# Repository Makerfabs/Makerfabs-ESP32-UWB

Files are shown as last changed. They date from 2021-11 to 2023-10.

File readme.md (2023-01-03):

# Makerfabs ESP32 UWB & Display

```c++
/*
Version:		V4.3
Author:			Vincent
Create Date:	2021/11/6
Note:
	2021/12/9 	V2.0:Add a Indoor Positioning demo.
	2022/6/29 	V2.1:Add DW3000 library.
	2022/8/1  	V3.0:Provides a library available for high-power versions. Move DW3000 to other 		  					     repositories.
	2022/9/6	V3.1:Added changes to the high-power version.
	2022/10/26 	V4.0:Add new version with SSD1306
	2022/11/15	V4.1:Change library name to mf_DW1000.zip
	2022/12/29	V4.2: Change wiki link
	2023/1/3	V4.3: Change directory name.
*/
```
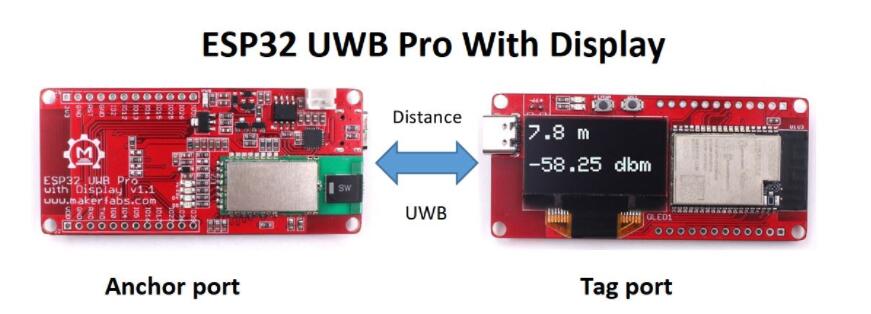
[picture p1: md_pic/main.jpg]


[toc]

# Makerfabs

[Makerfabs home page](https://www.makerfabs.com/)

[Makerfabs Wiki](https://wiki.makerfabs.com/)

# Makerfabs ESP32 UWB Serials
## Intruduce

ESP32 UWB : [esp32-uwb-ultra-wideband](https://www.makerfabs.com/esp32-uwb-ultra-wideband.html) 

ESP32 UWB Pro : [esp32-uwb-high-power](https://www.makerfabs.com/esp32-uwb-high-power-120m.html)

ESP32 UWB Pro with Display : [ESP32 UWB Pro with Display](https://www.makerfabs.com/esp32-uwb-pro-with-display.html)

Wiki Link : [ESP32 UWB Pro with Display](https://wiki.makerfabs.com/ESP32_UWB_Pro_with_Display.html) 

Ultra-wideband (UWB) is a short-range, wireless communication protocol that operates through radio waves, enables secure reliable ranging and precision sensing, creating a new dimension of spatial context for wireless devices.

This new ESP32 UWB pro with display is the updated version of ESP32 UWB Pro, with the following new spec:

- On-board OLED, 1.3” 128*64, so the distance results can be directly displayed
- Lipo battery charger& connector, so this module can work separately with batteries
- Update UWB position, so the module can be directly installed into a case

| | **UWB Basic** | **UWB Pro** | **UWB Pro with Display** | **UWB DW3000** |
| --- | --- | --- | --- | --- |
| CPU | ESP32-WROOM/WROVER | ESP32-WROVER | ESP32-WROVER | ESP32-WROOM/WROVER |
| Core UWB | DW1000 | DW1000 | DW1000 | DW3000 |
| Screen | N | N | Y | N |
| Measuring distance(m) | 45 | 200 | 200 | 20 |
| Battery Socket | N | N | Y | N |
| UWB Channel | 2/5 | 2/5 | 2/5 | 5/9 |
| Apple Interoperable | N | N | N | Y |
| Suitable for | Normal Testing | Long distance needed | Long distance needed | Product development |

### UWB Basic

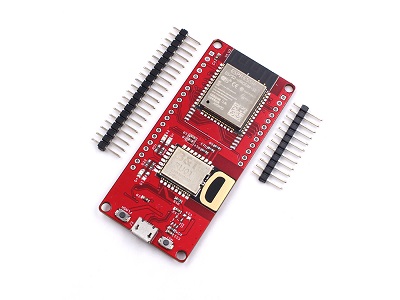
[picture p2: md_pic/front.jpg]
front


### UWB Pro

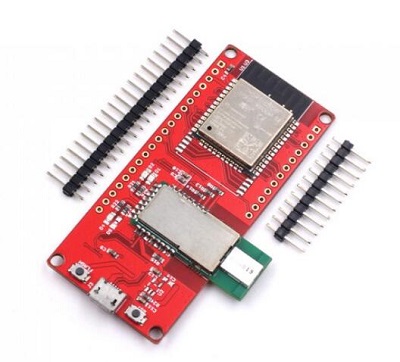
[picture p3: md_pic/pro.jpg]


### UWB Pro with Display

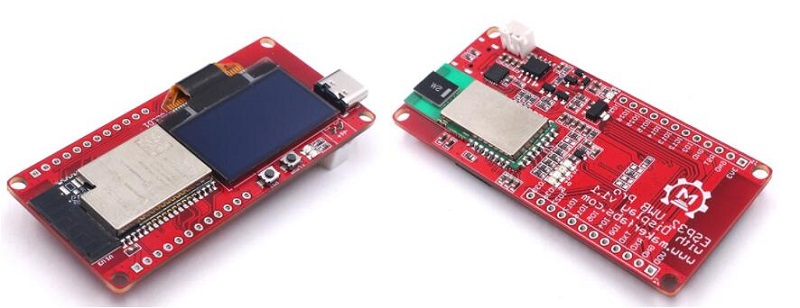
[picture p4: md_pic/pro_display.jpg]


# Example

## Compiler Options

**If you have any questions，such as how to install the development board, how to download the code, how to install the library. Please refer to :[Makerfabs_FAQ](https://github.com/Makerfabs/Makerfabs_FAQ)**

- Install board : ESP32 .
- Rename mf_DW1000.zip to DW1000.zip and install it.
- Install library : Adafruit_SSD1306
- Upload code, select board "ESP32 DEV"

**This library was modified from the [DW1000](https://github.com/thotro/arduino-dw1000) library to work with the Makerfabs hardware. **

**Please download the latest version from our Github.**

## Example List

### uwb_tag

*For ESP32 UWB and ESP32 UWB Pro*

Distance to the receiving end of the test. You need an anchor point to receive data.

### uwb_tag_display

*For ESP32 UWB Pro with display*

Distance to the receiving end of the test. You need an anchor point to receive data.

### anchor

*For ESP32 UWB and ESP32 UWB Pro*

Distance test anchor point.

### anchor_display

*For ESP32 UWB Pro with display*

Distance test anchor point.

### Indoor positioning

*For ESP32 UWB and ESP32 UWB Pro*

Three UWB modules were used for indoor plane positioning. Data is transmitted through UDP protocol and graphically displayed in Python. 

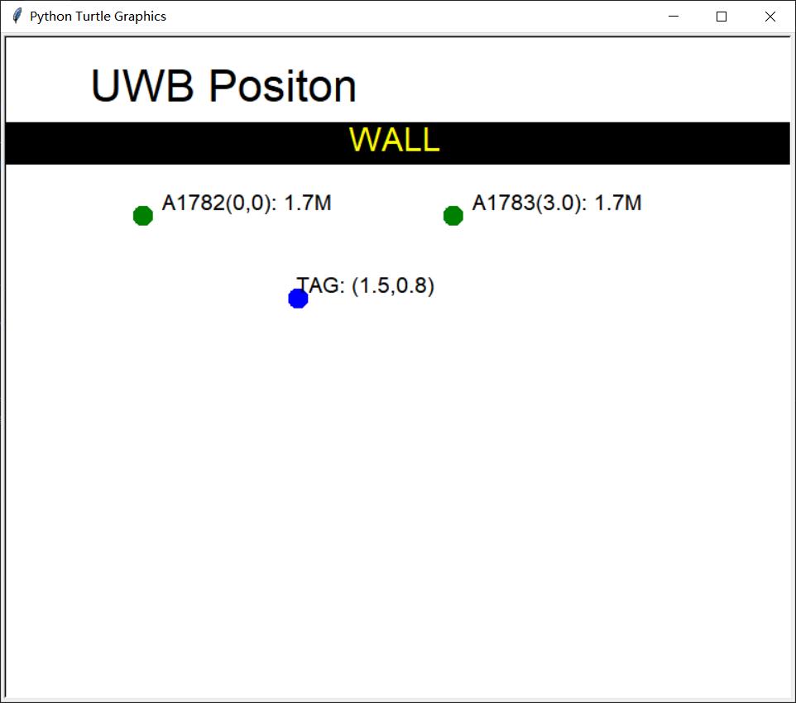
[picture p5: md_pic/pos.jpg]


The law of cosines is used to calculate tag coordinates.

```python
def tag_pos(a, b, c):
    # p = (a + b + c) / 2.0
    # s = cmath.sqrt(p * (p - a) * (p - b) * (p - c))
    # y = 2.0 * s / c
    # x = cmath.sqrt(b * b - y * y)
    cos_a = (b * b + c*c - a * a) / (2 * b * c)
    x = b * cos_a
    y = b * cmath.sqrt(1 - cos_a * cos_a)

    return round(x.real, 1), round(y.real, 1)
```

## Pin Define

### ESP32 UWB and ESP32 UWB Pro

```c++
#define SPI_SCK 18
#define SPI_MISO 19
#define SPI_MOSI 23

#define DW_CS 4
#define PIN_RST 27
#define PIN_IRQ 34
```

### ESP32 Pro with display

```c++
#define SPI_SCK 18
#define SPI_MISO 19
#define SPI_MOSI 23

#define UWB_SS 21   // spi select pin
#define UWB_RST 27  // reset pin
#define UWB_IRQ 34  // irq pin

#define I2C_SDA 4	//I2C screen ssd1306
#define I2C_SCL 5
```

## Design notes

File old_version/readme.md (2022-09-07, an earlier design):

# Makerfabs ESP32 UWB

```c++
/*
Version:		V3.0
Author:			Vincent
Create Date:	2021/11/6
Note:
	2021/12/9 	V2.0:Add a Indoor Positioning demo.
	2022/6/29 	V2.1:Add DW3000 library.
	2022/8/1  	V3.0:Provides a library available for high-power versions. Move DW3000 to other 		  					     repositories.
	2022/9/6	V3.1:Added changes to the high-power version.

*/
```


[toc]

# Makerfabs

[Makerfabs home page](https://www.makerfabs.com/)

[Makerfabs Wiki](https://makerfabs.com/wiki/index.php?title=Main_Page)

# Makerfabs ESP32 UWB
## Intruduce

Product Link ：[esp32-uwb-ultra-wideband](https://www.makerfabs.com/esp32-uwb-ultra-wideband.html) 

Wiki Link : [ESP32_UWB](https://www.makerfabs.com/wiki/index.php?title=ESP32_UWB) 

Makerfabs ESP32 UWB contains an ESP32 and a DW1000 chip.

The DW1000 is a single-chip wireless transceiver based on ultra-wideband technology. The chip enables you to develop cost-effective RTLS solutions that can pinpoint indoor and outdoor positioning to within 10 cm.

The chip provides a new approach to real-time location and indoor location systems, location-based services, wireless sensor networks and the Internet of Things by providing accurate location awareness and communication.

UWB - X1 - PRO module is our decaWave DW1000 chip design company based UWB transceiver module products. After the encapsulation All compatible DWM1000, pin pin to pin, can directly replace to use. The antenna is integrated in the module and all of the rf circuit, power management and clock circuit is equal to one.

Based on our actual tests, the range range of the standard DW1000 is around 47 meters, and the long-distance version can reach 125 meters. Of course, it depends on the test environment.

## Feature

- Integrated ESP32 2.4G WiFi and Bluetooth.
- DW1000 UWB module.
- UWB - X1 - PRO module.(Long range)

### Front:

front

### Back:
back

### Long Range Version UWB-X1-Pro

long

# Example

## Equipment list

- At least two ESP32 UWB

## Compiler Options

**If you have any questions，such as how to install the development board, how to download the code, how to install the library. Please refer to :[Makerfabs_FAQ](https://github.com/Makerfabs/Makerfabs_FAQ)**

- Install board : ESP32 .
- Install library : arduino-dw1000
- Change code in DW1000.cpp

```c++
void DW1000Class::begin(uint8_t irq, uint8_t rst) {
	// generous initial init/wake-up-idle delay
	delay(5);
	// Configure the IRQ pin as INPUT. Required for correct interrupt setting for ESP8266
    	pinMode(irq, INPUT);
	// start SPI
	SPI.begin();

// Change By VINCENT
// #ifndef ESP8266
// 	SPI.usingInterrupt(digitalPinToInterrupt(irq)); // not every board support this, e.g. ESP8266
// #endif

	// pin and basic member setup
	_rst        = rst;
	_irq        = irq;
	_deviceMode = IDLE_MODE;
	// attach interrupt
	//attachInterrupt(_irq, DW1000Class::handleInterrupt, CHANGE); // todo interrupt for ESP8266
	// TODO throw error if pin is not a interrupt pin
	attachInterrupt(digitalPinToInterrupt(_irq), DW1000Class::handleInterrupt, RISING); // todo interrupt for ESP8266
}
```

Comment out these code, or a compilation error will occur.

```c++
// #ifndef ESP8266
// 	SPI.usingInterrupt(digitalPinToInterrupt(irq)); // not every board support this, e.g. ESP8266
// #endif
```

- Upload code, select board "ESP32 DEV"

**V3.0 Update**

Modify by [DW1000](https://github.com/thotro/arduino-dw1000) version 0.9.0

Provides a library available for high-power versions. It is also compatible with the standard DW1000, and in fact only adds an initialization function for the high-power version. Of course, it also includes the changes above.

```c++

// Vincent changes
// For large power moudle
void DW1000Class::large_power_init()
{
	// uint32 reg;
	// reg = dwt_read32bitreg(GPIO_CTRL_ID);
	// reg |= 0x00014000;
	// reg |= 0x00050000;
	// dwt_write32bitreg(GPIO_CTRL_ID, reg);
	// dwt_write16bitoffsetreg(PMSC_ID, PMSC_TXFINESEQ_OFFSET, PMSC_TXFINESEQ_DISABLE);

	byte reg[4];

	readBytes(GPIO_CTRL, 0, reg, 4);

	reg[1] |= 0x40;
	reg[2] |= 0x01;
	reg[2] |= 0x05;

	writeBytes(GPIO_CTRL, 0, reg, 4);

	reg[0] = reg[1] = reg[2] = reg[3] = 0;
	writeBytes(PMSC, 0x26, reg, 2);

	reg[0] = 0xC0;
	reg[1] = 0;
	reg[2] = 0;
	reg[3] = 0;
	writeBytes(TX_CAL, TC_PGDELAY_SUB, reg, 1);

	reg[0] = 0x1f;
	reg[1] = 0x1f;
	reg[2] = 0x1f;
	reg[3] = 0x1f;
	writeBytes(TX_POWER, 0, reg, 4);
}
```

**V3.1 Update**

By changing the channel from Channel5 to Channel2, the distance of UWB-X1-Pro can reach 320M.



This is due to the fact that the X1-Pro's antenna is optimized for Channel2.

But Makerfabs could not provide further technical support, just suggestions from suppliers.

If you're interested, try DW1000_channel2.zip, or make changes directly in the DW1000 library code.





## Example List

### Anchor

Distance test anchor point.

### Tag

Distance to the receiving end of the test. You need an anchor point to receive data.

### Tag_1306

There is an SSD1306 screen receiver, and a data structure for storing multiple anchor points is implemented. (The screen can display a maximum of two anchors, you can modify the font size to show more anchors). You need an anchor point to receive data.

### Indoor positioning

Three UWB modules were used for indoor plane positioning. Data is transmitted through UDP protocol and graphically displayed in Python. 



The law of cosines is used to calculate tag coordinates.

```python
def tag_pos(a, b, c):
    # p = (a + b + c) / 2.0
    # s = cmath.sqrt(p * (p - a) * (p - b) * (p - c))
    # y = 2.0 * s / c
    # x = cmath.sqrt(b * b - y * y)
    cos_a = (b * b + c*c - a * a) / (2 * b * c)
    x = b * cos_a
    y = b * cmath.sqrt(1 - cos_a * cos_a)

    return round(x.real, 1), round(y.real, 1)
```

## Code Explain

- Define Pins

```c++
#define SPI_SCK 18
#define SPI_MISO 19
#define SPI_MOSI 23
#define DW_CS 4

// connection pins
const uint8_t PIN_RST = 27; // reset pin
const uint8_t PIN_IRQ = 34; // irq pin
const uint8_t PIN_SS = 4;   // spi select pin
```

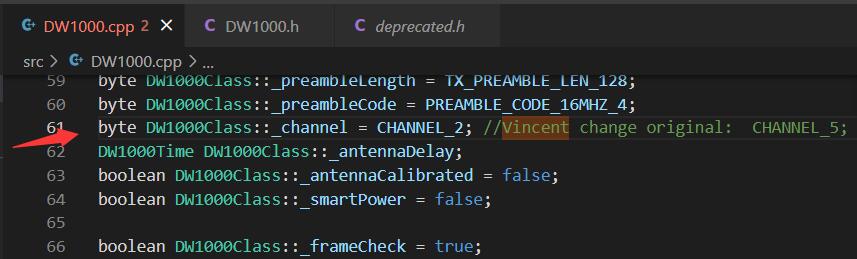
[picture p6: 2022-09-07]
md_pic/v2.jpg

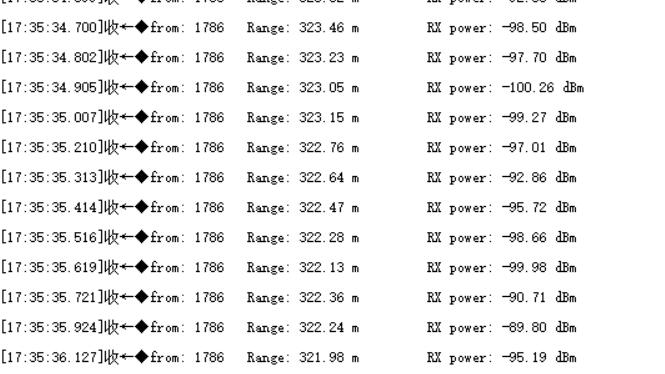
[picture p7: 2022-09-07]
md_pic/pro320m.jpg

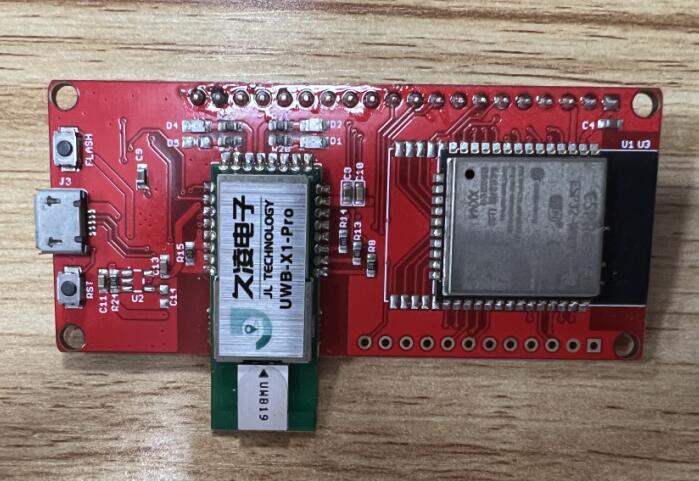
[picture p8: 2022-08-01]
md_pic/long.jpg

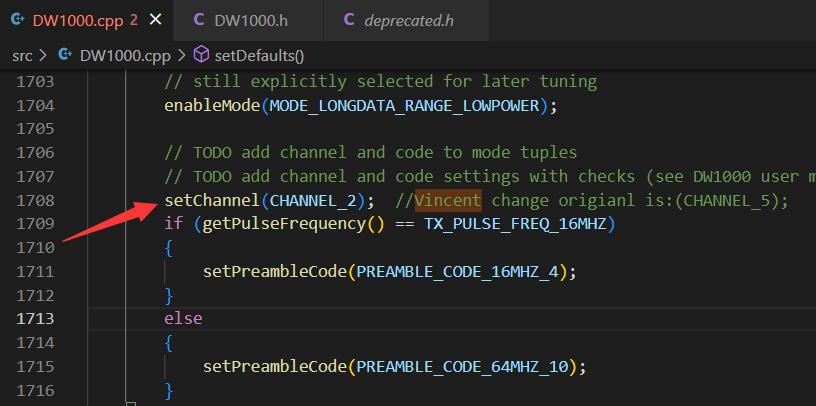
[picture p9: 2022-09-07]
md_pic/v1.jpg

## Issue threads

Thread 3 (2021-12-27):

Apple devices UWB?

exrector, 2021-12-27:
What about iPhone, Apple Watch, AirTag?
It would be nice to use your board as an anchor and my apple devices.  Set the radius and run the required routines from the esp32 repositories.

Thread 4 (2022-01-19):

Antenna tuning / calibration accuracy

alastaira, 2022-01-19:
Hi,

The board design seems good, but I'm getting poor accuracy on the range readings (i.e. when the distance between anchor and tag is consistently reading around 50cm too high). From reading the Decawave documentation, there is an application note regarding antenna calibration, which suggests this could be resolved in either software or hardware design: https://www.decawave.com/wp-content/uploads/2018/10/APS014_Antennna-Delay-Calibration_V1.2.pdf - is that something you've accounted for at all, or can suggest how to incorporate in the library?

Cheers,

pbs-websuntangled, 2022-01-19:
Agreed.i get the same

Also readings are somewhat inconsistent. Rotating the tag or anchor through 90 degrees can add or remove 200mm from the distance reported

Fbo06, 2022-11-03:
hello, got the same issue, do you have found a solution ? thank you for your response

alastaira, 2022-11-03:
> hello, got the same issue, do you have found a solution ? thank you for your response

No, I gave up I'm afraid. Unfortunately I think these boards are not useful for anything other than toys :(

franciscoQM, 2022-11-29:
I came across the same issue. Although I am constantly getting an error of about 0.6 - 0.7+ meters I tested in a distance of from 0-125 meters. I wonder if anyone has found a way of improving the error. For my application all I need is .5 meters

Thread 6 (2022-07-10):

Issues with integrating other SPI devices (?)

XPloadED, 2022-07-10:
Hi,
I'm trying to combine the UWB ranging with the Waveshare 2.9" e-paper display, which also uses SPI. Right now I'm not really sure whats causing the issues. (Maybe conflicting pins? Blocking code somewhere between libraries?).
The Library used for e-paper  display is "GxEPD".
The SPI definition was unchanged in my testings:
```
GxIO_Class io(SPI, /*CS=5*/ SS, /*DC=*/ 17, /*RST=*/ 16); // arbitrary selection of 17, 16
GxEPD_Class display(io, /*RST=*/ 16, /*BUSY=*/ 4); // arbitrary selection of (16), 4
```
As long as I dont run (from GxEPD Lib):
`display.init(115200);`
Ranging works fine, but as soon as I try to combine them I get this multiple times, instead of ranging:

```
Guru Meditation Error: Core  1 panic'ed (Interrupt wdt timeout on CPU1).

Core  1 register dump:
PC      : 0x4008a716  PS      : 0x00060d35  A0      : 0x8008996e  A1      : 0x3ffbedbc
A2      : 0x3ffb7f54  A3      : 0x3ffb8890  A4      : 0x00000004  A5      : 0x00060d23
A6      : 0x00060d23  A7      : 0x00000001  A8      : 0x3ffb8890  A9      : 0x00000018
A10     : 0x3ffb8890  A11     : 0x00000018  A12     : 0x3ffc3414  A13     : 0x00060d23
A14     : 0x007bef68  A15     : 0x003fffff  SAR     : 0x0000001e  EXCCAUSE: 0x00000006
EXCVADDR: 0x00000000  LBEG    : 0x40085e74  LEND    : 0x40085e79  LCOUNT  : 0x00000000
Core  1 was running in ISR context:
EPC1    : 0x400e16d3  EPC2    : 0x00000000  EPC3    : 0x00000000  EPC4    : 0x00000000

Backtrace:0x4008a713:0x3ffbedbc |<-CORRUPTED

Core  0 register dump:
PC      : 0x4008a893  PS      : 0x00060035  A0      : 0x80089597  A1      : 0x3ffbe8bc
A2      : 0x3ffbef68  A3      : 0xb33fffff  A4      : 0x0000abab  A5      : 0x00060023
A6      : 0x00060021  A7      : 0x0000cdcd  A8      : 0x0000abab  A9      : 0xffffffff
A10     : 0x3ffc3230  A11     : 0x00000000  A12     : 0x3ffc322c  A13     : 0x00000007
A14     : 0x007bef68  A15     : 0x003fffff  SAR     : 0x0000001a  EXCCAUSE: 0x00000006
EXCVADDR: 0x00000000  LBEG    : 0x00000000  LEND    : 0x00000000  LCOUNT  : 0x00000000

Backtrace:0x4008a890:0x3ffbe8bc |<-CORRUPTED

ELF file SHA256: 0000000000000000

Rebooting...
```

I don't quite know where the issue is. I'm using this for an university project and am also planning on building another version with the new Apple compatible revision. Therefore I have to get this working somehow. I hope someone can help me out.
It's not necessarily an issue with this library, I just cant tell at the moment.

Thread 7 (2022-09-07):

problem with ESP connection

murtadhodaf, 2022-09-07:
i try to upload and compiling data and get this error

```
`Arduino: 1.8.19 (Windows Store 1.8.57.0) (Windows 10), Board: "ESP32 Dev Module, Disabled, Default 4MB with spiffs (1.2MB APP/1.5MB SPIFFS), 240MHz (WiFi/BT), QIO, 80MHz, 4MB (32Mb), 921600, Core 1, Core 1, None"

Sketch uses 240933 bytes (18%) of program storage space. Maximum is 1310720 bytes.
Global variables use 16376 bytes (4%) of dynamic memory, leaving 311304 bytes for local variables. Maximum is 327680 bytes.
esptool.py v3.3
Serial port COM3
Connecting.....................................An error occurred while uploading the sketch
.

A fatal error occurred: Failed to connect to ESP32: Wrong boot mode detected (0x13)! The chip needs to be in download mode.
For troubleshooting steps visit: https://docs.espressif.com/projects/esptool/en/latest/troubleshooting.html`
```
 It try to reset with the sreset button and doesn' work shat should i do ? thx

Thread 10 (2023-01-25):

Watchdog issue on SPI IRC

JulienCarayon, 2023-01-25:
It seems that this line in the DW1000 library is causing issue :

```
attachInterrupt(digitalPinToInterrupt(_irq), DW1000Class::handleInterrupt, RISING);
```
It's causing bootloop and triggers a timout watchdog

Thank you for you help, it would be much much appreciated !

here is the log i have :
```
--- Terminal on /dev/cu.usbserial-028D4616 | 115200 8-N-1
--- Available filters and text transformations: colorize, debug, default, direct, esp32_exception_decoder, hexlify, log2file, nocontrol, printable, send_on_enter, time
--- More details at https://bit.ly/pio-monitor-filters
--- Quit: Ctrl+C | Menu: Ctrl+T | Help: Ctrl+T followed by Ctrl+H
3fff0030,len:1184
load:0x40078000,len:13160
load:0x40080400,len:3036
entry 0x400805e4
E (97) psram: PSRAM ID read error: 0xffffffff
Guru Meditation Error: Core  1 panic'ed (Interrupt wdt timeout on CPU1).

Core  1 register dump:
PC      : 0x4008b9c0  PS      : 0x00060735  A0      : 0x8008ac12  A1      : 0x3ffbed2c
A2      : 0x3ffb7f54  A3      : 0x3ffb8890  A4      : 0x00000004  A5      : 0x00060723
A6      : 0x00060723  A7      : 0x00000001  A8      : 0x3ffb8890  A9      : 0x00000018
A10     : 0x3ffb8890  A11     : 0x00000018  A12     : 0x3ffc1d04  A13     : 0x00060723
A14     : 0x007beed8  A15     : 0x003fffff  SAR     : 0x0000001e  EXCCAUSE: 0x00000006
EXCVADDR: 0x00000000  LBEG    : 0x4008537d  LEND    : 0x40085385  LCOUNT  : 0x00000027
Core  1 was running in ISR context:
EPC1    : 0x400e04b3  EPC2    : 0x00000000  EPC3    : 0x00000000  EPC4    : 0x00000000

Backtrace:0x4008b9bd:0x3ffbed2c |<-CORRUPTED

Core  0 register dump:
PC      : 0x4008bb37  PS      : 0x00060035  A0      : 0x8008a83b  A1      : 0x3ffbe82c
A2      : 0x3ffbeed8  A3      : 0xb33fffff  A4      : 0x0000abab  A5      : 0x00060023
A6      : 0x00060021  A7      : 0x0000cdcd  A8      : 0x0000abab  A9      : 0xffffffff
A10     : 0x3ffc1af0  A11     : 0x00000000  A12     : 0x3ffc1aec  A13     : 0x00000007
A14     : 0x007beed8  A15     : 0x003fffff  SAR     : 0x0000001a  EXCCAUSE: 0x00000006
EXCVADDR: 0x00000000  LBEG    : 0x00000000  LEND    : 0x00000000  LCOUNT  : 0x00000000

Backtrace:0x4008bb34:0x3ffbe82c |<-CORRUPTED

ELF file SHA256: 0000000000000000
```

I've used platformIO to compile with the following versions :
```
Processing esp32dev (platform: espressif32; board: esp32dev; framework: arduino)
---------------------------------------------------------------------------------------------------------------------------------------------
Verbose mode can be enabled via `-v, --verbose` option
CONFIGURATION: https://docs.platformio.org/page/boards/espressif32/esp32dev.html
PLATFORM: Espressif 32 (6.0.0) > Espressif ESP32 Dev Module
HARDWARE: ESP32 240MHz, 320KB RAM, 4MB Flash
DEBUG: Current (cmsis-dap) External (cmsis-dap, esp-bridge, esp-prog, iot-bus-jtag, jlink, minimodule, olimex-arm-usb-ocd, olimex-arm-usb-ocd-h, olimex-arm-usb-tiny-h, olimex-jtag-tiny, tumpa)
PACKAGES:
 - framework-arduinoespressif32 @ 3.20006.221224 (2.0.6)
 - tool-esptoolpy @ 1.40400.0 (4.4.0)
 - toolchain-xtensa-esp32 @ 8.4.0+2021r2-patch5

 ```

gwilsonOSU, 2023-02-08:
I encountered the same issue using the provided example anchor.ino.  I believe the bug is in the following line of code:

`const uint8_t PIN_SS = 22;   // spi select pin`

Changing the pin assignment from 22 to 4 (as it is in the tag version of the code) fixed the issue for me.  The anchor now receives ranges from a tag.

Closed 2023-02-09.

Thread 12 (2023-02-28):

Usb connector part

djObsidian, 2023-02-28:
What is this footprint? I can't find any suitable part for this footprint. The closest avaliable thing was 2013499-1 from TE Connectivity, but its legs are spaced wider than should be here.
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
Part name in schematic is just MICRO-USB-5P, it makes no sense.

greg1985, 2025-04-23:
I know its an old issue, but its still opened and I have encountered same problem so...
Seems it might be U254-051T-4BH83-S1S

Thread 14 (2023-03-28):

The example code can't work with ESP32 UWB Pro with Display

willy20040711, 2023-03-28:
I try to use 3 ESP32 UWB Pro with Display boards. Two anchors and one for tag.
The example code of [indoorIndoorPositioning](https://github.com/Makerfabs/Makerfabs-ESP32-UWB/tree/main/example/IndoorPositioning)  can't work.
The tag only return empty object like: {LINK:[]}

juanelog, 2023-10-26:
Hi Willy
Did you find any solution to this problem?

> I try to use 3 ESP32 UWB Pro with Display boards. Two anchors and one for tag. The example code of [indoorIndoorPositioning](https://github.com/Makerfabs/Makerfabs-ESP32-UWB/tree/main/example/IndoorPositioning) can't work. The tag only return empty object like: {LINK:[]}

I'm trying to do indoor positioning but I have the same result.
Do you have any recommendations?
Thank you

lewthomps, 2023-11-24:
same issue here!

We're either of you able to find a solution to this problem?

Thanks!

lewthomps, 2023-11-24:
nevermind! switchting DW_CS pin to 21 fixed the problem!

scinfu, 2024-01-17:
not working for me change the pint to 21.
I have bought this: https://www.makerfabs.com/mauwb-dw3000-with-stm32-at-command.html

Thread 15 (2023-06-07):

Whera are the LED connected to?

Nachorov027, 2023-06-07:
Hi, I've recently bought 4 of these device for an indoor location project and I've seen that the board has a couple LEDs I would like to use to give some indications. Which signals of the ESP32 controls these leds??

Thx in advance for your help
Alejandro

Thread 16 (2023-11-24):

Guru Meditation Error: Core  1 panic'ed (Interrupt wdt timeout on CPU1) using ESP32 anchor example code

lewthomps, 2023-11-24:
Hi All,

I'm using a Mac running Monterey and attempting to run the [example code](https://github.com/Makerfabs/Makerfabs-ESP32-UWB/blob/main/example/IndoorPositioning/anchor/anchor.ino) on Arduino IDE for the [ESP32 UWB](https://www.makerfabs.com/esp32-uwb-ultra-wideband.html), but it runs into this error:

```
Guru Meditation Error: Core  1 panic'ed (Interrupt wdt timeout on CPU1).

Core  1 register dump:
PC      : 0x4008ac3a  PS      : 0x00060735  A0      : 0x80089bb2  A1      : 0x3ffbf18c
A2      : 0x3ffb7d84  A3      : 0x3ffbd330  A4      : 0x00000004  A5      : 0x00060723
A6      : 0x00060723  A7      : 0x00000001  A8      : 0x3ffbd330  A9      : 0x00000018
A10     : 0x3ffbd330  A11     : 0x00000018  A12     : 0x3ffc2794  A13     : 0x00060723
A14     : 0x007bf338  A15     : 0x003fffff  SAR     : 0x0000001e  EXCCAUSE: 0x00000006
EXCVADDR: 0x00000000  LBEG    : 0x400841e1  LEND    : 0x400841e9  LCOUNT  : 0x00000027
Core  1 was running in ISR context:
EPC1    : 0x400dfb6b  EPC2    : 0x00000000  EPC3    : 0x00000000  EPC4    : 0x00000000

Backtrace: 0x4008ac37:0x3ffbf18c |<-CORRUPTED

Core  0 register dump:
```

I did not touch the code. It is straight copied and pasted from the git repository, which led me to believe it would work without a hitch!

It seems to have an issue with this line:
`
DW1000Ranging.initCommunication(PIN_RST, PIN_SS, PIN_IRQ);
`
But I can't figure out why or what needs to be changed to get this code to run correctly.

Any help would be greatly appreciated!!!

Best
Lewis

kaiming-uw, 2024-07-09:
@lewthomps Hi Lewis, I encountered the same problem when running the ESP32 anchor code. I wonder if you have any insights on fixing this bug, thanks!

cicintrip, 2025-01-14:
how did you solve it?
I'm having the same problem :(

Closed 2023-11-24.

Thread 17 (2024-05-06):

Missing schematic for "UWB Pro with Display v1.1"

StohanzlMart, 2024-05-06:
Please add (or explain the difference between) hardware schematic for "UWB Pro with Display" v1.1 and v1.2 or 1.0.

Thank you!

PS: Maybe upload pdfs of all version schematics.

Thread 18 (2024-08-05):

Issue with the limited uwb range in existing code

rachanaa04, 2024-08-05:
I am currently working on a project using the UWB modules from Makerfabs and have been utilizing the UWB codes provided in the official Makerfabs GitHub repository. According to the product specifications on your website, the expected range of these UWB modules is over 100 meters. However, in my tests, I am consistently getting a limited range of only 3.7 to 4 meters.
Here are some details of my setup:
1.I am using the same UWB codes as provided in the Makerfabs repository.
2.The environment for testing is open and free of obstacles that might interfere with the UWB signal.
3.I have followed all the setup instructions as per the documentation.

Any solutions for this ?

Vorstok, 2025-04-04:
Hi, I had a similar problem, you need to experiment with the driver DW1000.cpp

I got it working after replacing this:

byte DW1000Class::_preambleCode = PREAMBLE_CODE_16MHZ_4;
byte DW1000Class::_channel = CHANNEL_5;

It was replaced with this:

byte DW1000Class::_preambleCode = PREAMBLE_CODE_16MHZ_2;
byte DW1000Class::_channel = CHANNEL_1;

Juli-blip-creator, 2025-07-16:
Hi, I am having the same Problem. Also changed Channel and MHZ but it won´t work.

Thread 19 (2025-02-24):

ESP32 UWB Pro – Signal Reliability Issues

pasandal, 2025-02-24:
Hi,

I have a setup using two ESP32 UWB Pros, one as an anchor and the other as a tag, but I'm struggling to achieve the desired signal reliability.

In both of your UWB PRO demo videos, it seems that when the person carries the tag, their body partially obstructs the line of sight. However, the signal reliability and range performance remain strong. I attempted a similar setup, but when I turn around, I lose the signal almost instantly.

I've tried holding the tag at least 30 cm away from my body, yet I still experience frequent dropouts. My testing range is between 2–5 meters, and I’ve experimented with different supported modes, such as MODE_LONGDATA_RANGE_ACCURACY and MODE_LONGDATA_FAST_ACCURACY, but I haven't been able to achieve the same performance shown in your videos.

Could you share which mode was used in your demos? Additionally, is there anything else I should consider to improve my setup?

UWB PRO demo videos:
https://www.youtube.com/watch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

https://www.youtube.com/watch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

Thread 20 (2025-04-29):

Struggling to Achieve Promised Range with ESP32 UWB Pro High-Power Modules

Jo-drc, 2025-04-29:
I have purchased 5 ESP32 UWB Pro modules from Makerfabs, but unfortunately, I am not able to achieve the range stated on their website. I have followed all the instructions as described and even made changes in the DW1000.cpp file, replacing:

byte DW1000Class::_preambleCode = PREAMBLE_CODE_16MHZ_4;
byte DW1000Class::_channel = CHANNEL_5;

with:

byte DW1000Class::_preambleCode = PREAMBLE_CODE_16MHZ_2;
byte DW1000Class::_channel = CHANNEL_1;

But even after implementing it, I can only achieve a range of 8 meters. Moreover, the reported signal strength is around -70 dBm, even when the devices are as close as 20 cm to each other.

Thank you in advance for any advice or suggestions.

Juli-blip-creator, 2025-07-16:
Hi, I am having the exact same Problem if you found any solution please let me know! :)

Juli-blip-creator, 2025-07-18:
Hi, just found a solution!

Jo-drc, 2025-07-18:
Apologies for the delayed response. I wasn’t able to find a viable solution, so I’ve decided to put the project on hold indefinitely. May I ask what approach you’ve taken to resolve the issue?

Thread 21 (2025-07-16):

Not achieving Promised Range with ESP32 UWB Pro High-Power

Juli-blip-creator, 2025-07-16:
Hi,
I’m using the Makerfabs UWB DW1000 Pro with OLED display for a ranging project.
When I run the ranging code (both the provided examples and my own test code), I only get distances between about 2 m and 12 m.
Beyond that, no range is reported, or the readings become completely unstable.

What I’ve already tried

Checked and reseated all connections and antennas.

Tested with different power supplies.

Used the suggestions from other issues.

Tested indoor and outdoor to avoid reflections.

Expected behavior
I would expect at least ~100 m (or more) in open space as mentioned in the product description.

Closed 2025-07-18.

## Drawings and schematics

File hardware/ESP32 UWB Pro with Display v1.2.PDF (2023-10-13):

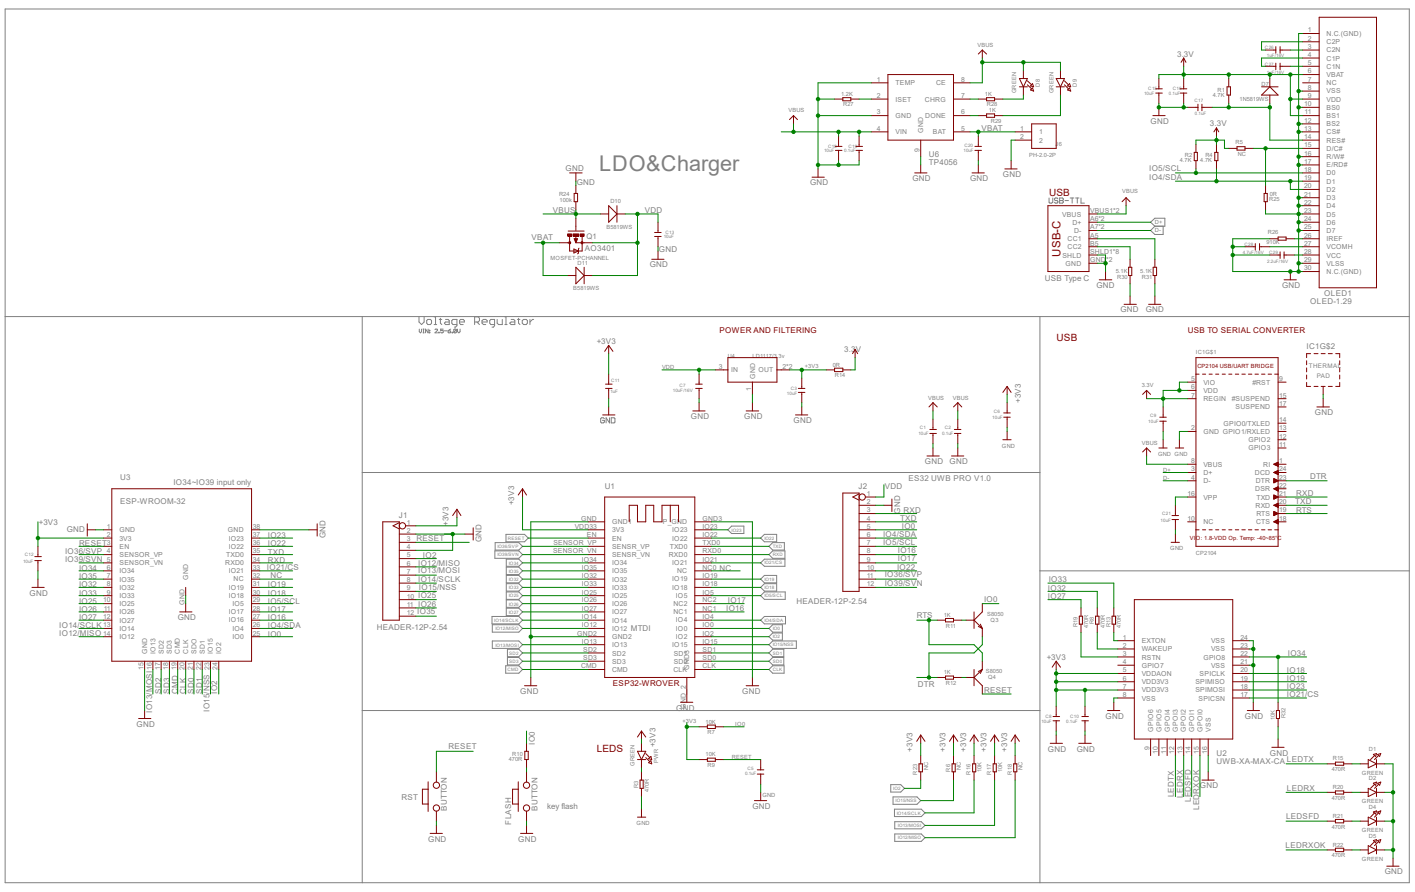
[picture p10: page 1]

USB Type C LDO&Charger

D1 19
D2 20

VIO: 1.8-VDD Op. Temp: -40~85°C USB⁻C

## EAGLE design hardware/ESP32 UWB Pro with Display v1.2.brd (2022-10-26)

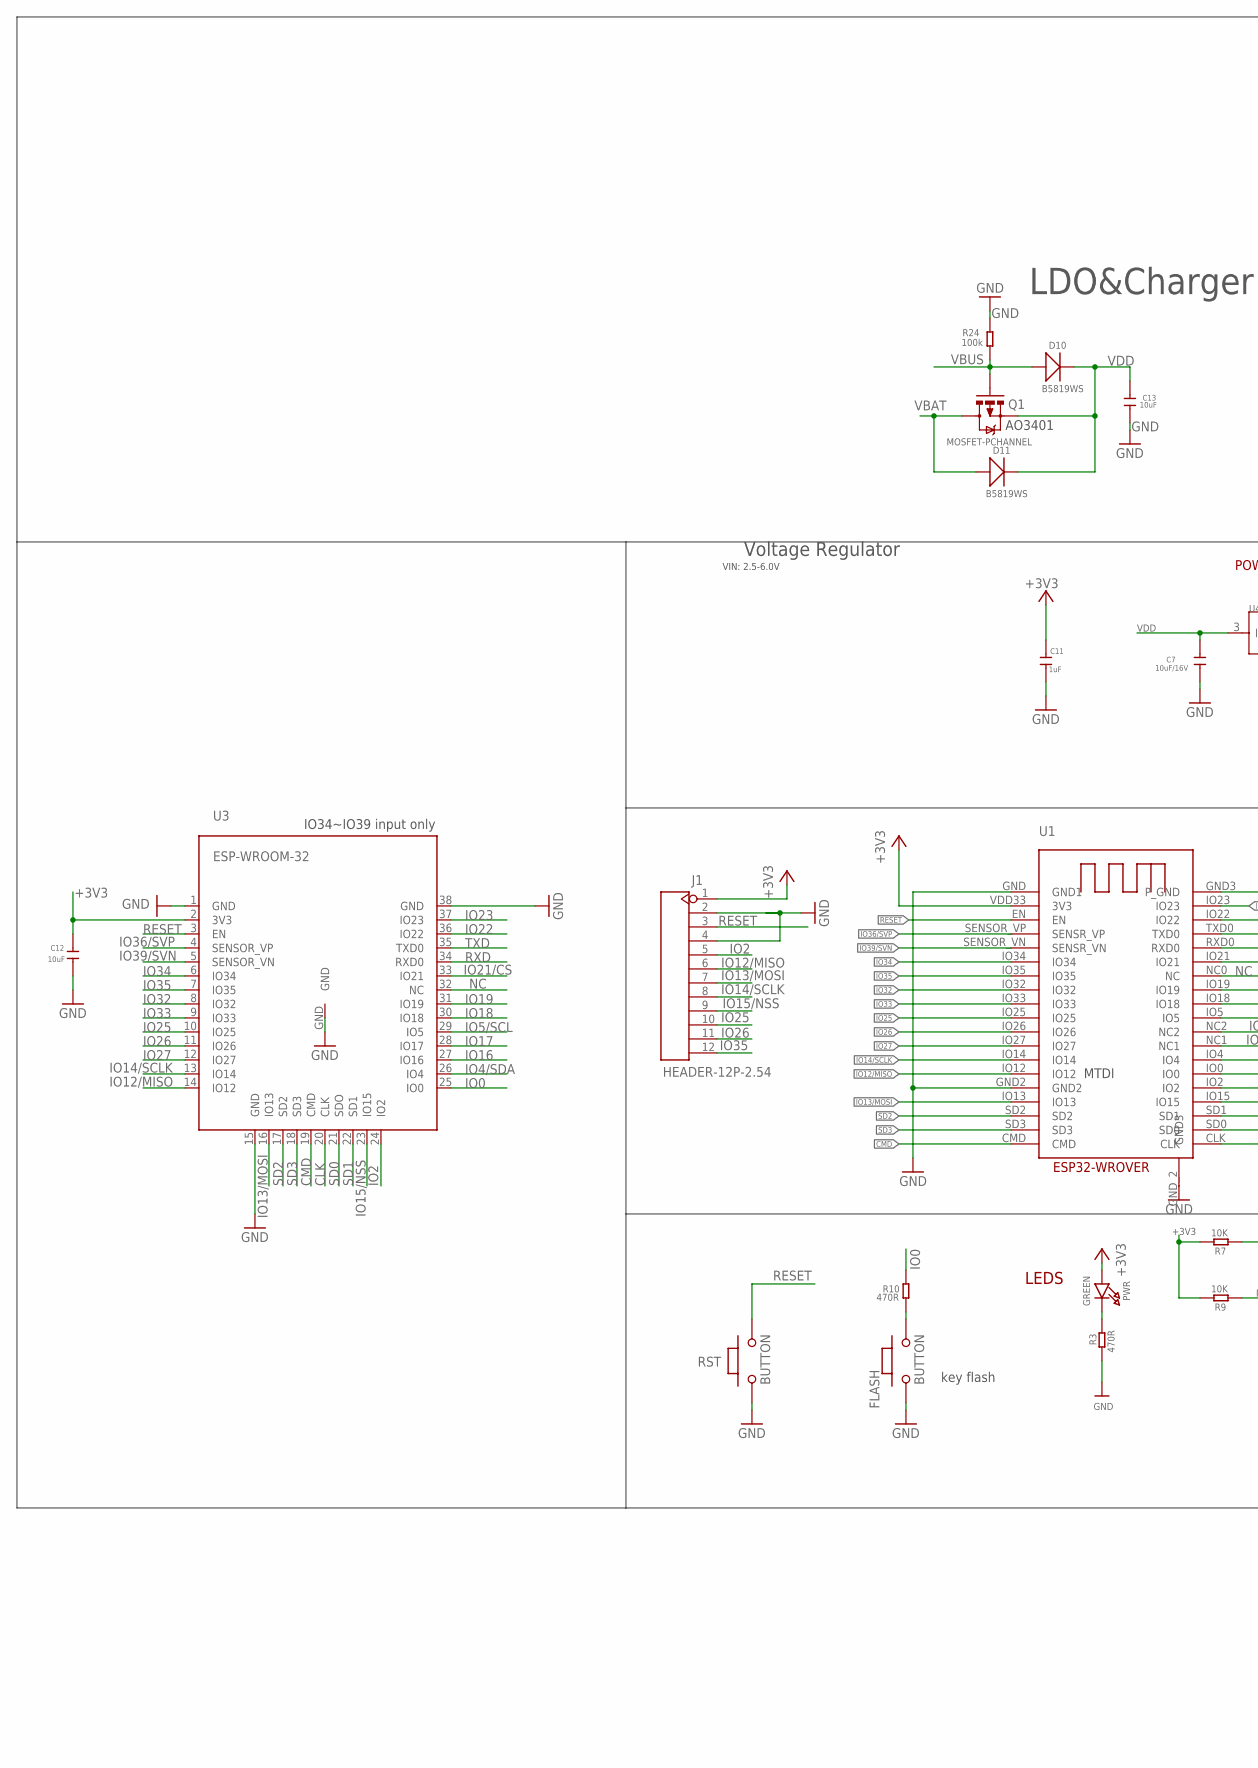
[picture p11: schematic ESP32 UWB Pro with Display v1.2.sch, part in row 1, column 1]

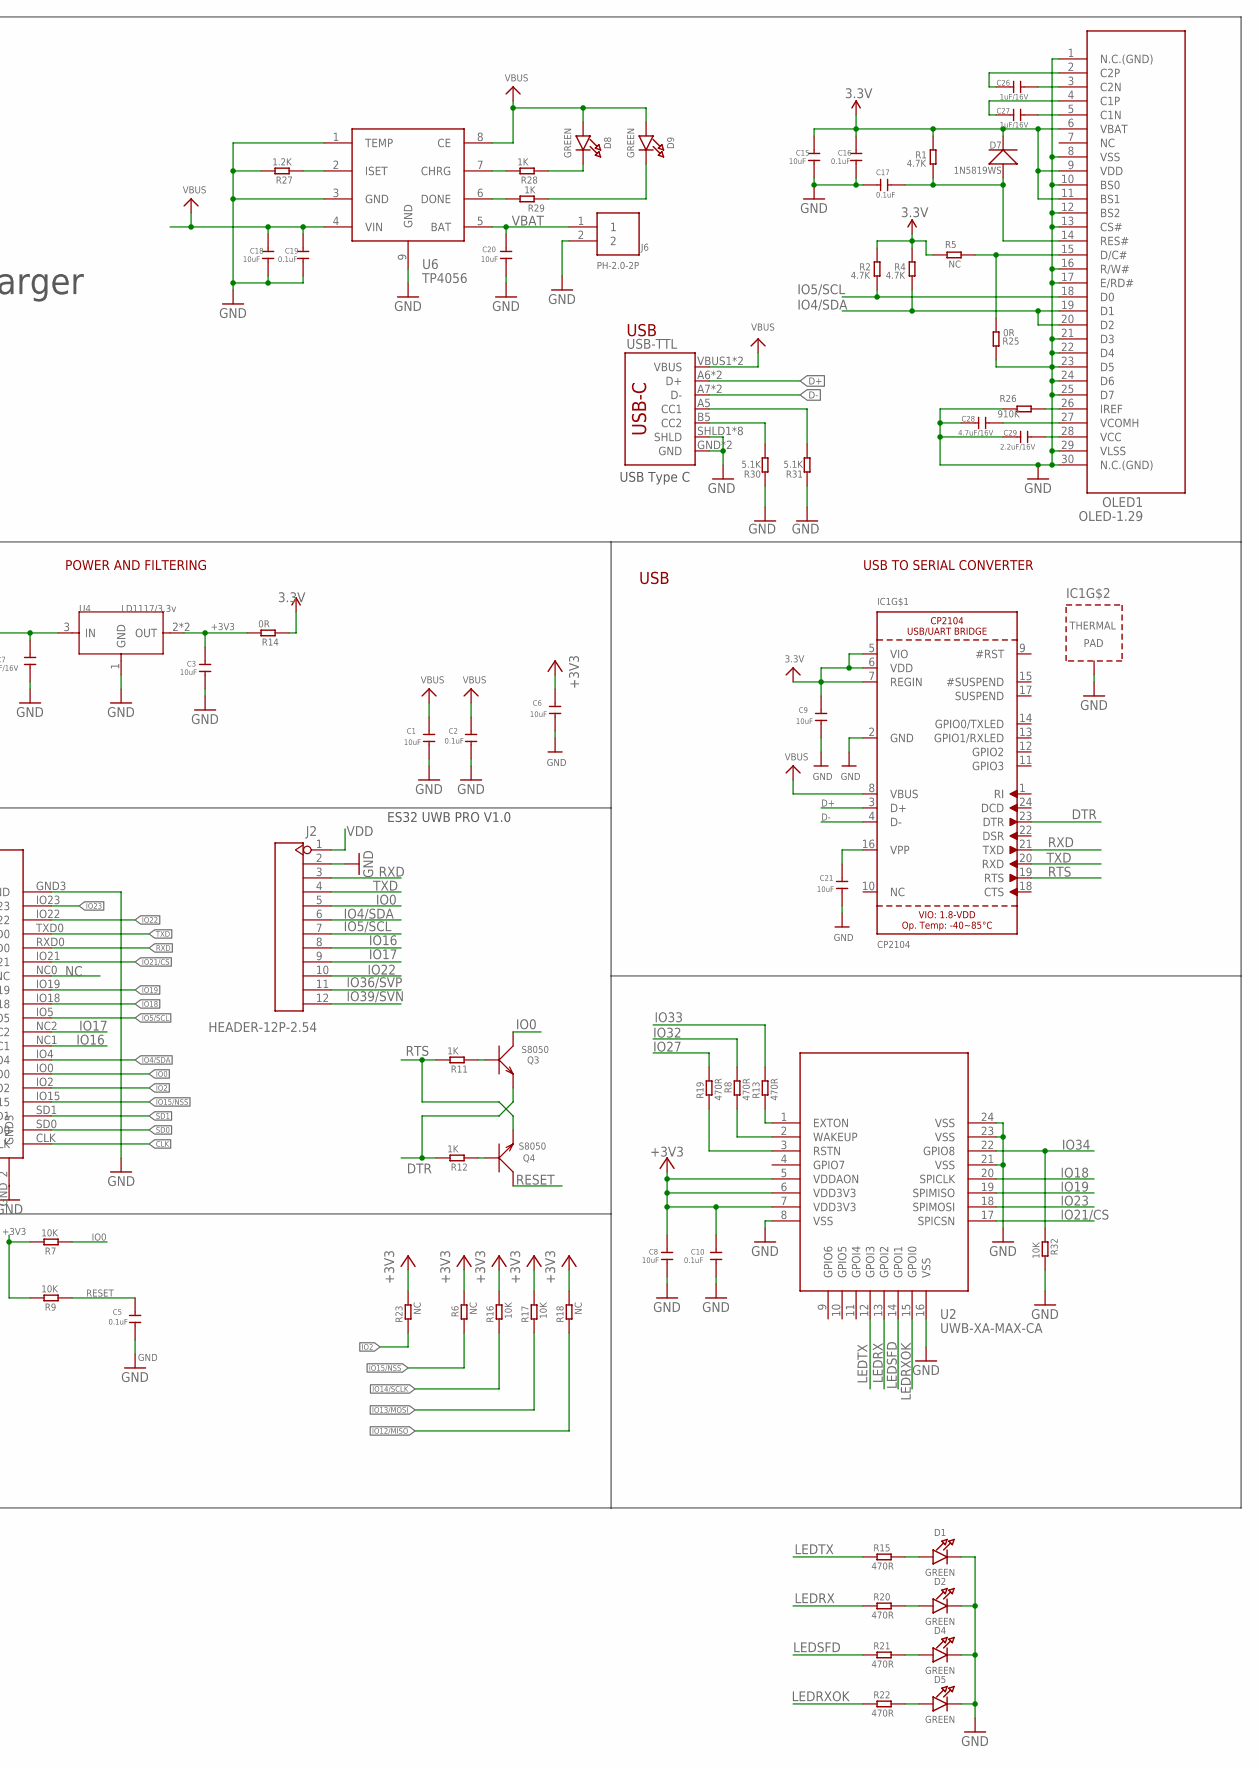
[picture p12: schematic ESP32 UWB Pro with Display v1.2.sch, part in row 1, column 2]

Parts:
C1, C3, C6, C8, C9, C12, C13, C15, C18, C20, C21: 10uF; 0603
C2, C5, C10, C16, C17, C19: 0.1uF; 0603
C7: 10uF/16V; 0603
C11: 1uF; 0603
C26, C27: 1uF/16V; 0603
C28: 4.7uF/16V; 0603
C29: 2.2uF/16V; 0603
D1, D2, D4, D5, D8, D9: GREEN; CHIPLED_0805_NOOUTLINE
D7: 1N5819WS; SOD323
D10, D11: B5819WS; SOD323
FLASH: BUTTON; 157SW
IC1: CP2104; QFN24_4MM_SMSC
J1, J2: HEADER-12P-2.54; 12P-2.54
J6: PH-2.0-2P
OLED1: OLED-1.29
PWR: GREEN; CHIPLED_0805_NOOUTLINE
Q1: MOSFET-PCHANNEL; SOT23-3
Q3, Q4: S8050; SOT23
R1, R2, R4: 4.7K; R0603
R3, R8, R10, R13, R15, R19, R20, R21, R22: 470R; R0603
R5, R6, R18, R23: NC; R0603
R7, R9, R16, R17, R32: 10K; R0603
R11, R12, R28, R29: 1K; R0603
R14, R25: 0R; R0603
R24: 100k; R0603
R26: 910K; R0603
R27: 1.2K; R0603
R30, R31: 5.1K; DISCRETE_R0603
RST: BUTTON; 157SW
U1: ESP32-WROVER
U2: UWB-XA-MAX-CA; UWB-X1-MAK-CA
U3: ESP-WROOM-32
U4: LD1117/3.3v; SOT89
U6: TP4056; SOP8-1.27P
USB-TTL: USB_C5; USB-C-16P-5

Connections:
3.3V: C15.1, C16.1, D7.-, OLED1.6 (VBAT), OLED1.9 (VDD), OLED1.11 (BS1), R1.2, R2.2, R4.2, R5.2, R14.1
+3V3: C3.1, C6.1, C8.1, C9.1, C10.1, C11.1, C12.1, IC1.5 (VIO), IC1.6 (VDD), IC1.7 (REGIN), J1.1, PWR.A, R6.2, R7.2, R9.2, R14.2, R16.2, R17.2, R18.2, R23.2, U1.VDD33 (3V3), U2.5 (VDDAON), U2.6 (VDD3V3), U2.7 (VDD3V3), U3.2 (3V3), U4.2 (OUT), U4.4 (OUT)
CLK: U1.CLK, U3.20 (CLK)
CMD: U1.CMD, U3.19 (CMD)
D+: IC1.3 (D+), USB-TTL.A6 (D+), USB-TTL.B6 (D+)
D-: IC1.4 (D-), USB-TTL.A7 (D-), USB-TTL.B7 (D-)
DTR: IC1.23 (DTR), Q3.2 (E), R12.2
GND: C1.2, C2.2, C3.2, C5.2, C6.2, C7.2, C8.2, C9.2, C10.2, C11.2, C12.2, C13.1, C15.2, C16.2, C17.1, C18.2, C19.2, C20.2, C21.2, C28.1, C29.1, D1.C, D2.C, D4.C, D5.C, FLASH.1, IC1.2 (GND), IC1.THERM (TP), J1.2, J1.4, J2.2, J6.2, OLED1.1 (N.C.(GND)), OLED1.8 (VSS), OLED1.10 (BS0), OLED1.12 (BS2), OLED1.13 (CS#), OLED1.16 (R/W#), OLED1.17 (E/RD#), OLED1.21 (D3), OLED1.22 (D4), OLED1.23 (D5), OLED1.24 (D6), OLED1.25 (D7), OLED1.29 (VLSS), OLED1.30 (N.C.(GND)), R3.1, R24.2, R25.2, R26.2, R27.2, R30.1, R31.1, R32.2, RST.1, U1.GND (GND1), U1.GND2, U1.GND3 (P_GND), U1.GND_2 (GND3), U2.8 (VSS), U2.16 (VSS), U2.21 (VSS), U2.23 (VSS), U2.24 (VSS), U3.1 (GND), U3.15 (GND), U3.38 (GND), U3.GND, U4.1 (GND), U6.1 (TEMP), U6.3 (GND), U6.9 (GND), USB-TTL.GND, USB-TTL.GND2 (GND), USB-TTL.SHLD1 (SHLD), USB-TTL.SHLD2 (SHLD), USB-TTL.SHLD3 (SHLD), USB-TTL.SHLD4 (SHLD), USB-TTL.SHLD5 (SHLD), USB-TTL.SHLD6 (SHLD), USB-TTL.SHLD7 (SHLD), USB-TTL.SHLD8 (SHLD)
IO0: J2.5, Q3.3 (C), R7.1, R10.2, U1.IO0, U3.25 (IO0)
IO2: J1.5, R23.1, U1.IO2, U3.24 (IO2)
IO4/SDA: J2.6, OLED1.19 (D1), OLED1.20 (D2), R4.1, U1.IO4, U3.26 (IO4)
IO5/SCL: J2.7, OLED1.18 (D0), R2.1, U1.IO5, U3.29 (IO5)
IO12/MISO: J1.6, R18.1, U1.IO12, U3.14 (IO12)
IO13/MOSI: J1.7, R17.1, U1.IO13, U3.16 (IO13)
IO14/SCLK: J1.8, R16.1, U1.IO14, U3.13 (IO14)
IO15/NSS: J1.9, R6.1, U1.IO15, U3.23 (IO15)
IO16: J2.8, U1.NC1, U3.27 (IO16)
IO17: J2.9, U1.NC2, U3.28 (IO17)
IO18: U1.IO18, U2.20 (SPICLK), U3.30 (IO18)
IO19: U1.IO19, U2.19 (SPIMISO), U3.31 (IO19)
IO21/CS: U1.IO21, U2.17 (SPICSN), U3.33 (IO21)
IO22: J2.10, U1.IO22, U3.36 (IO22)
IO23: U1.IO23, U2.18 (SPIMOSI), U3.37 (IO23)
IO25: J1.10, U1.IO25, U3.10 (IO25)
IO26: J1.11, U1.IO26, U3.11 (IO26)
IO27: R19.2, U1.IO27, U3.12 (IO27)
IO32: R8.2, U1.IO32, U3.8 (IO32)
IO33: R13.2, U1.IO33, U3.9 (IO33)
IO34: R32.1, U1.IO34, U2.22 (GPIO8), U3.6 (IO34)
IO35: J1.12, U1.IO35, U3.7 (IO35)
IO36/SVP: J2.11, U1.SENSOR_VP (SENSR_VP), U3.4 (SENSOR_VP)
IO39/SVN: J2.12, U1.SENSOR_VN (SENSR_VN), U3.5 (SENSOR_VN)
LEDRX: R20.1, U2.13 (GPOI2)
LEDRXOK: R22.1, U2.15 (GPOI0)
LEDSFD: R21.1, U2.14 (GPOI1)
LEDTX: R15.1, U2.12 (GPOI3)
unnamed: D1.A, R15.2
unnamed: C21.1, IC1.16 (VPP)
unnamed: C17.2, D7.+, OLED1.14 (RES#), R1.1
unnamed: OLED1.15 (D/C#), R5.1, R25.1
unnamed: PWR.C, R3.2
unnamed: C28.2, OLED1.27 (VCOMH)
unnamed: C26.2, OLED1.3 (C2N)
unnamed: C29.2, OLED1.28 (VCC)
unnamed: OLED1.26 (IREF), R26.1
unnamed: R13.1, U2.1 (EXTON)
unnamed: R8.1, U2.2 (WAKEUP)
unnamed: R19.1, U2.3 (RSTN)
unnamed: Q4.1 (B), R12.1
unnamed: Q3.1 (B), R11.1
unnamed: FLASH.2, R10.1
unnamed: D2.A, R20.2
unnamed: D4.A, R21.2
unnamed: D5.A, R22.2
unnamed: C26.1, OLED1.2 (C2P)
unnamed: C27.1, OLED1.4 (C1P)
unnamed: C27.2, OLED1.5 (C1N)
unnamed: R27.1, U6.2 (ISET)
unnamed: R31.2, USB-TTL.A5 (CC1)
unnamed: R30.2, USB-TTL.B5 (CC2)
unnamed: R28.2, U6.7 (CHRG)
unnamed: R29.2, U6.6 (DONE)
unnamed: D8.C, R28.1
unnamed: D9.C, R29.1
NC: U1.NC0 (NC), U3.32 (NC)
RESET: C5.1, J1.3, Q4.3 (C), R9.1, RST.2, U1.EN, U3.3 (EN)
RTS: IC1.19 (RTS), Q4.2 (E), R11.2
RXD: IC1.21 (TXD), J2.3, U1.RXD0, U3.34 (RXD0)
SD0: U1.SD0, U3.21 (SDO)
SD1: U1.SD1, U3.22 (SD1)
SD2: U1.SD2, U3.17 (SD2)
SD3: U1.SD3, U3.18 (SD3)
TXD: IC1.20 (RXD), J2.4, U1.TXD0, U3.35 (TXD0)
VBAT: C20.1, D11.+, J6.1, Q1.3 (D), U6.5 (BAT)
VBUS: C1.1, C2.1, C18.1, C19.1, D8.A, D9.A, D10.+, IC1.8 (VBUS), Q1.1 (G), R24.1, U6.4 (VIN), U6.8 (CE), USB-TTL.VBUS1 (VBUS), USB-TTL.VBUS2 (VBUS)
VDD: C7.1, C13.2, D10.-, D11.-, J2.1, Q1.2 (S), U4.3 (IN)

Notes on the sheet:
USB
LEDS
POWER AND FILTERING
USB TO SERIAL CONVERTER
key flash
ES32 UWB PRO V1.0
MTDI
IO34~IO39 input only
Voltage Regulator
VIN: 2.5-6.0V
USB Type C
LDO&Charger
AO3401

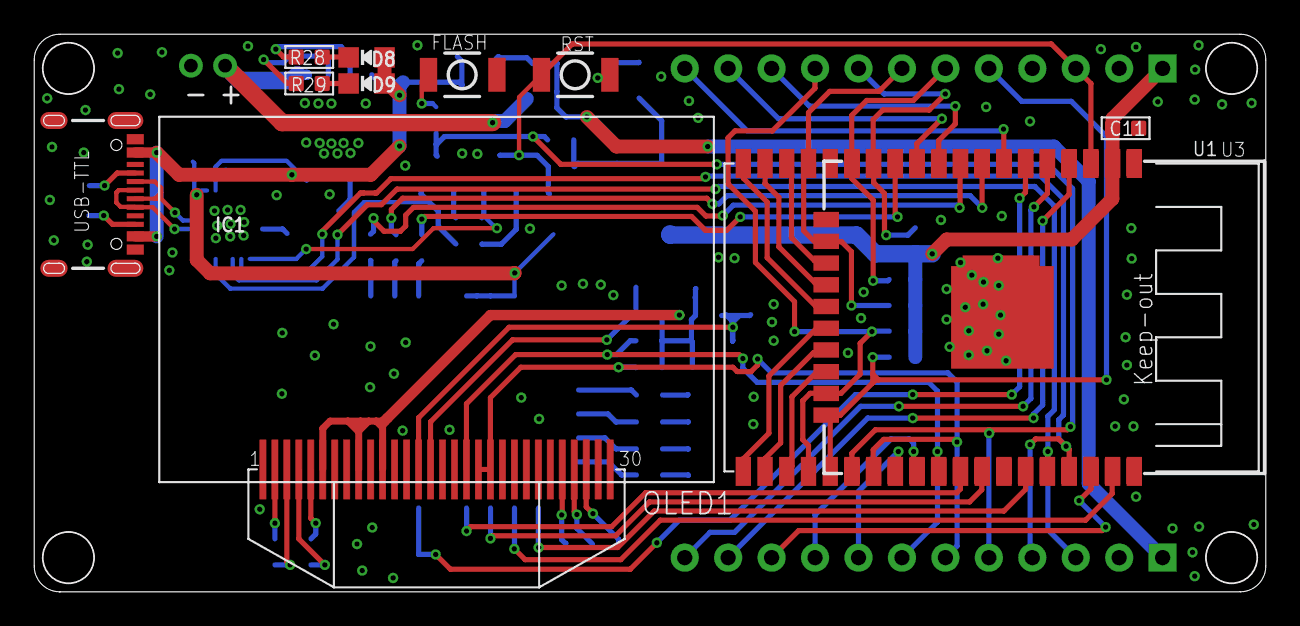
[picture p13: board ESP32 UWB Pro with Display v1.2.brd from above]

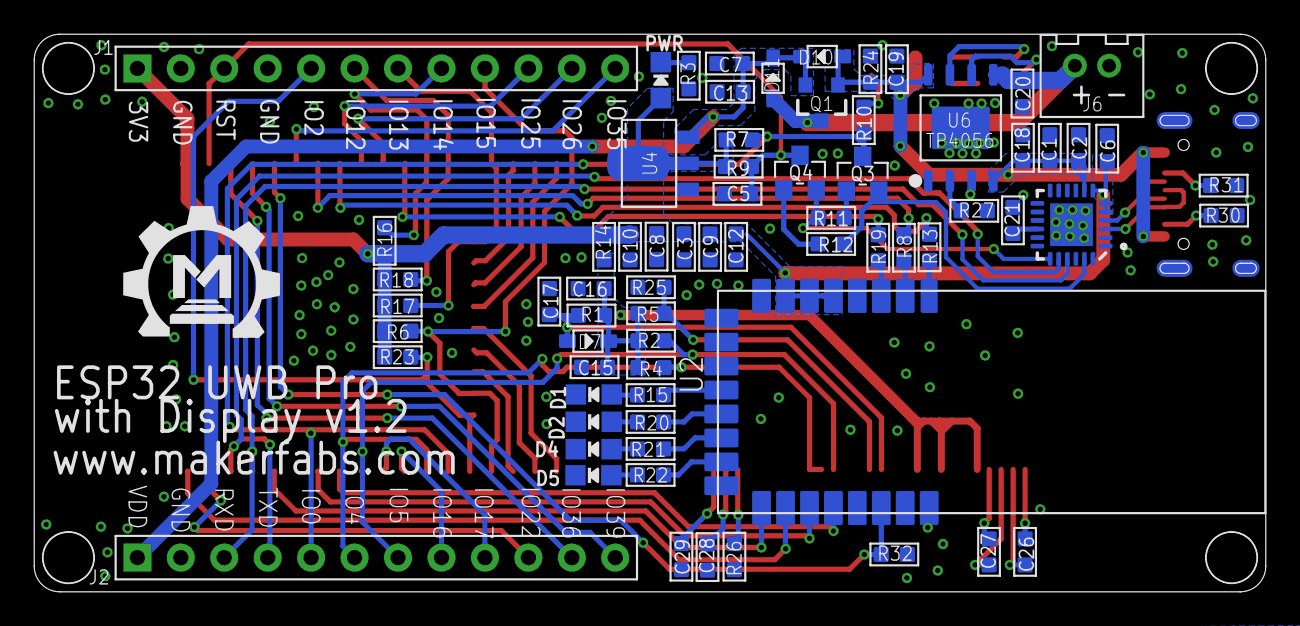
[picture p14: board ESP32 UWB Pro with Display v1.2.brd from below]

Board: 2 copper layers, 72.0 x 32.6 mm, 82 parts (71 on the bottom side), 76 nets.

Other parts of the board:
U$1: MAKERFABS_0.3

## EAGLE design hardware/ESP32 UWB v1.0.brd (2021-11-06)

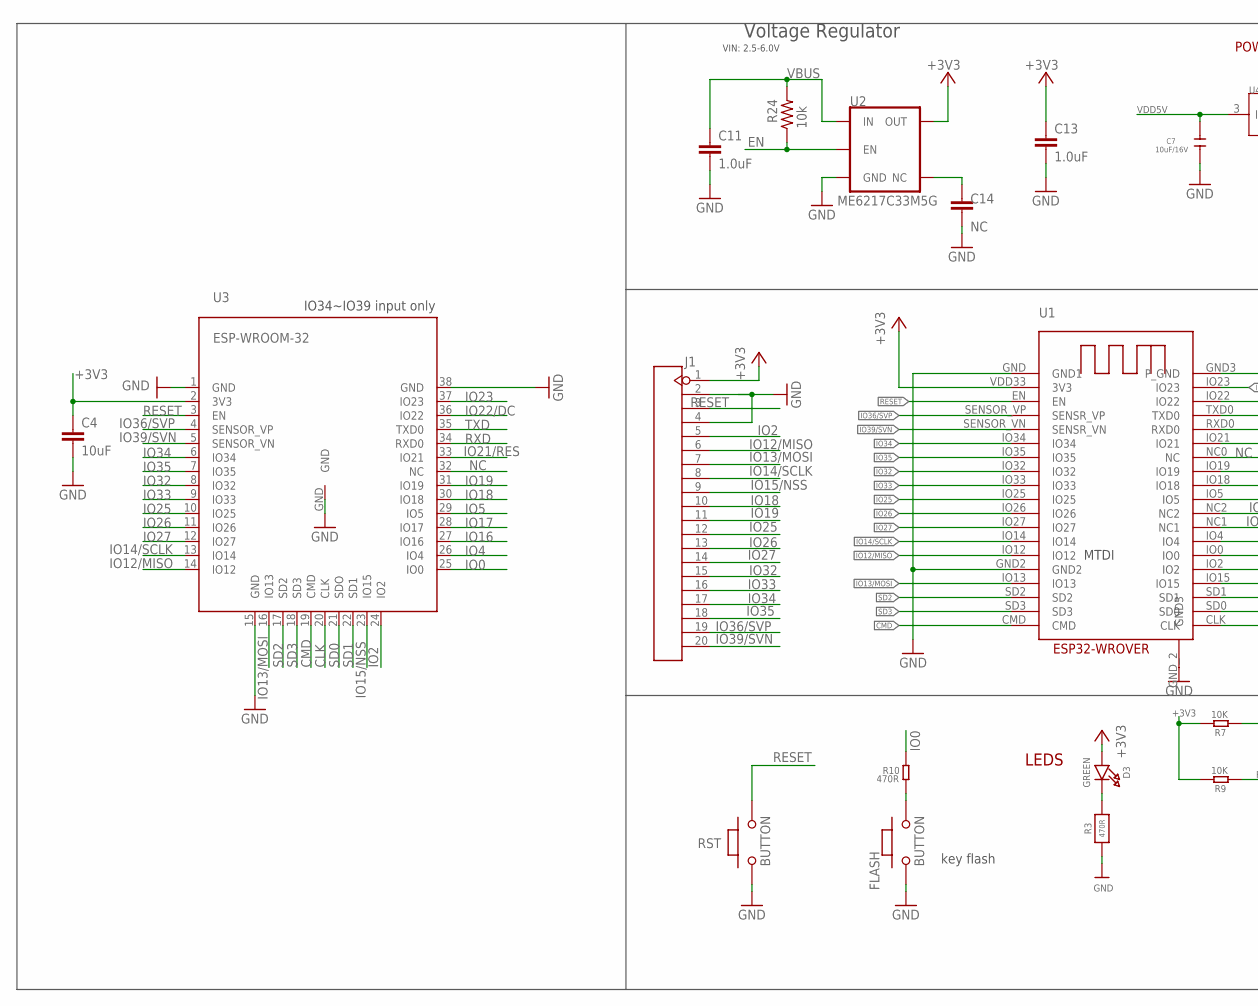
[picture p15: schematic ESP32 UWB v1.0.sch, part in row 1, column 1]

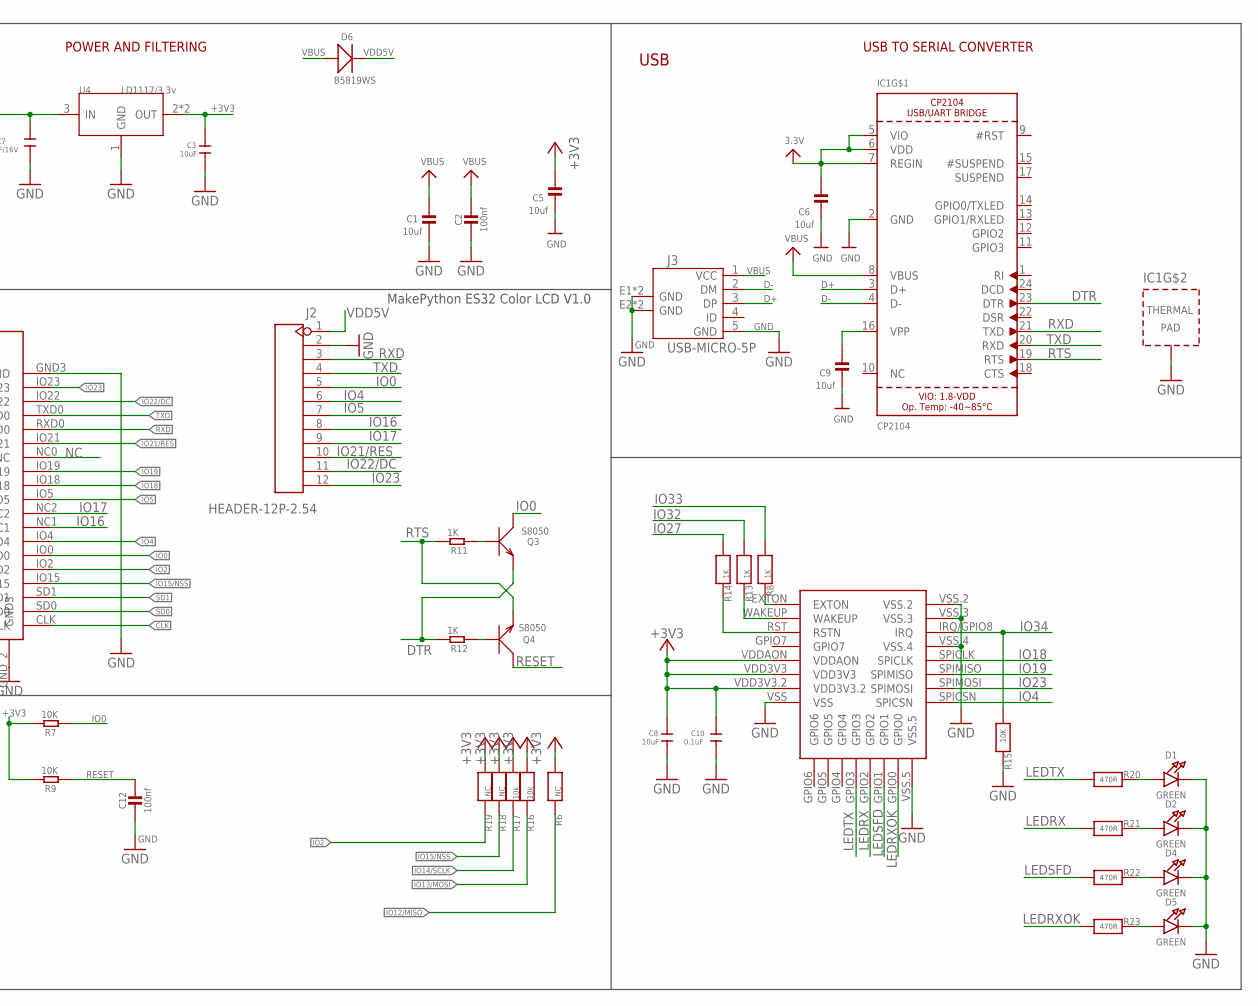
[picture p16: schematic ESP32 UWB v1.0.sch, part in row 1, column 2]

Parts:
C1, C5, C6, C9: 10uf; 0603-NO
C2, C12: 100nf; 0603-NO
C3, C4, C8: 10uF; C0603
C7: 10uF/16V; C0603
C10: 0.1uF; C0603
C11, C13: 1.0uF; 0603
C14: NC; 0603
D1, D2, D3, D4, D5: GREEN; CHIPLED_0805_NOOUTLINE
D6: B5819WS; SOD323
FLASH: BUTTON; 157SW
IC1: CP2104; QFN24_4MM_SMSC
J1: HEADER-20P-2.54; 20P-2.54
J2: HEADER-12P-2.54; 12P-2.54
J3: USB-MICRO-5P; MICRO-USB-5P
Q3, Q4: S8050; SOT23
R3, R20, R21, R22, R23: 470R; 0603-NO
R6, R18, R19: NC; 0603-NO
R7, R9: 10K; 0603
R8, R13, R14: 1K; 0603-NO
R10: 470R; 0603
R11, R12: 1K; 0603
R15: 10K; 0603-NO
R16, R17: 10k; 0603-NO
R24: 10k; 0603
RST: BUTTON; 157SW
U1: ESP32-WROVER
U2: ME6217C33M5G; SOT23-5
U3: ESP-WROOM-32
U4: LD1117/3.3v; SOT89
U5: DWM1000

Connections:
+3V3: C3.1, C4.1, C5.1, C6.1, C8.1, C10.1, C13.1, D3.A, IC1.5 (VIO), IC1.6 (VDD), IC1.7 (REGIN), J1.1, R6.1, R7.2, R9.2, R16.1, R17.1, R18.1, R19.1, U1.VDD33 (3V3), U2.5 (OUT), U3.2 (3V3), U4.2 (OUT), U4.4 (OUT), U5.VDD3V3, U5.VDD3V3.2, U5.VDDAON
CLK: U1.CLK, U3.20 (CLK)
CMD: U1.CMD, U3.19 (CMD)
D+: IC1.3 (D+), J3.3 (DP)
D-: IC1.4 (D-), J3.2 (DM)
DTR: IC1.23 (DTR), Q3.2 (E), R12.2
EN: R24.1, U2.3 (EN)
GND: C1.2, C2.2, C3.2, C4.2, C5.2, C6.2, C7.2, C8.2, C9.2, C10.2, C11.2, C12.2, C13.2, C14.2, D1.C, D2.C, D4.C, D5.C, FLASH.1, IC1.2 (GND), IC1.THERM (TP), J1.2, J1.4, J2.2, J3.5 (GND), J3.E1 (GND), J3.E2 (GND), J3.P1 (GND), J3.P2 (GND), R3.1, R15.2, RST.1, U1.GND (GND1), U1.GND2, U1.GND3 (P_GND), U1.GND_2 (GND3), U2.2 (GND), U3.1 (GND), U3.15 (GND), U3.38 (GND), U3.GND, U4.1 (GND), U5.VSS, U5.VSS.2, U5.VSS.3, U5.VSS.4, U5.VSS.5
IO0: J2.5, Q3.3 (C), R7.1, R10.2, U1.IO0, U3.25 (IO0)
IO2: J1.5, R19.2, U1.IO2, U3.24 (IO2)
IO4: J2.6, U1.IO4, U3.26 (IO4), U5.SPICSN
IO5: J2.7, U1.IO5, U3.29 (IO5)
IO12/MISO: J1.6, R6.2, U1.IO12, U3.14 (IO12)
IO13/MOSI: J1.7, R16.2, U1.IO13, U3.16 (IO13)
IO14/SCLK: J1.8, R17.2, U1.IO14, U3.13 (IO14)
IO15/NSS: J1.9, R18.2, U1.IO15, U3.23 (IO15)
IO16: J2.8, U1.NC1, U3.27 (IO16)
IO17: J2.9, U1.NC2, U3.28 (IO17)
IO18: J1.10, U1.IO18, U3.30 (IO18), U5.SPICLK
IO19: J1.11, U1.IO19, U3.31 (IO19), U5.SPIMISO
IO21/RES: J2.10, U1.IO21, U3.33 (IO21)
IO22/DC: J2.11, U1.IO22, U3.36 (IO22)
IO23: J2.12, U1.IO23, U3.37 (IO23), U5.SPIMOSI
IO25: J1.12, U1.IO25, U3.10 (IO25)
IO26: J1.13, U1.IO26, U3.11 (IO26)
IO27: J1.14, R14.1, U1.IO27, U3.12 (IO27)
IO32: J1.15, R13.1, U1.IO32, U3.8 (IO32)
IO33: J1.16, R8.1, U1.IO33, U3.9 (IO33)
IO34: J1.17, R15.1, U1.IO34, U3.6 (IO34), U5.IRQ/GPIO8 (IRQ)
IO35: J1.18, U1.IO35, U3.7 (IO35)
IO36/SVP: J1.19, U1.SENSOR_VP (SENSR_VP), U3.4 (SENSOR_VP)
IO39/SVN: J1.20, U1.SENSOR_VN (SENSR_VN), U3.5 (SENSOR_VN)
LEDRX: R21.1, U5.GPIO2
LEDRXOK: R23.1, U5.GPIO0
LEDSFD: R22.1, U5.GPIO1
LEDTX: R20.1, U5.GPIO3
unnamed: D1.A, R20.2
unnamed: C9.1, IC1.16 (VPP)
unnamed: C14.1, U2.4 (NC)
unnamed: D3.C, R3.2
unnamed: R8.2, U5.EXTON
unnamed: R13.2, U5.WAKEUP
unnamed: R14.2, U5.RST (RSTN)
unnamed: Q4.1 (B), R12.1
unnamed: Q3.1 (B), R11.1
unnamed: FLASH.2, R10.1
unnamed: D2.A, R21.2
unnamed: D4.A, R22.2
unnamed: D5.A, R23.2
NC: U1.NC0 (NC), U3.32 (NC)
RESET: C12.1, J1.3, Q4.3 (C), R9.1, RST.2, U1.EN, U3.3 (EN)
RTS: IC1.19 (RTS), Q4.2 (E), R11.2
RXD: IC1.21 (TXD), J2.3, U1.RXD0, U3.34 (RXD0)
SD0: U1.SD0, U3.21 (SDO)
SD1: U1.SD1, U3.22 (SD1)
SD2: U1.SD2, U3.17 (SD2)
SD3: U1.SD3, U3.18 (SD3)
TXD: IC1.20 (RXD), J2.4, U1.TXD0, U3.35 (TXD0)
VBUS: C1.1, C2.1, C11.1, D6.+, IC1.8 (VBUS), J3.1 (VCC), R24.2, U2.1 (IN)
VDD5V: C7.1, D6.-, J2.1, U4.3 (IN)

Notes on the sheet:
USB
LEDS
POWER AND FILTERING
USB TO SERIAL CONVERTER
key flash
MakePython ES32 Color LCD V1.0
MTDI
IO34~IO39 input only
Voltage Regulator
VIN: 2.5-6.0V

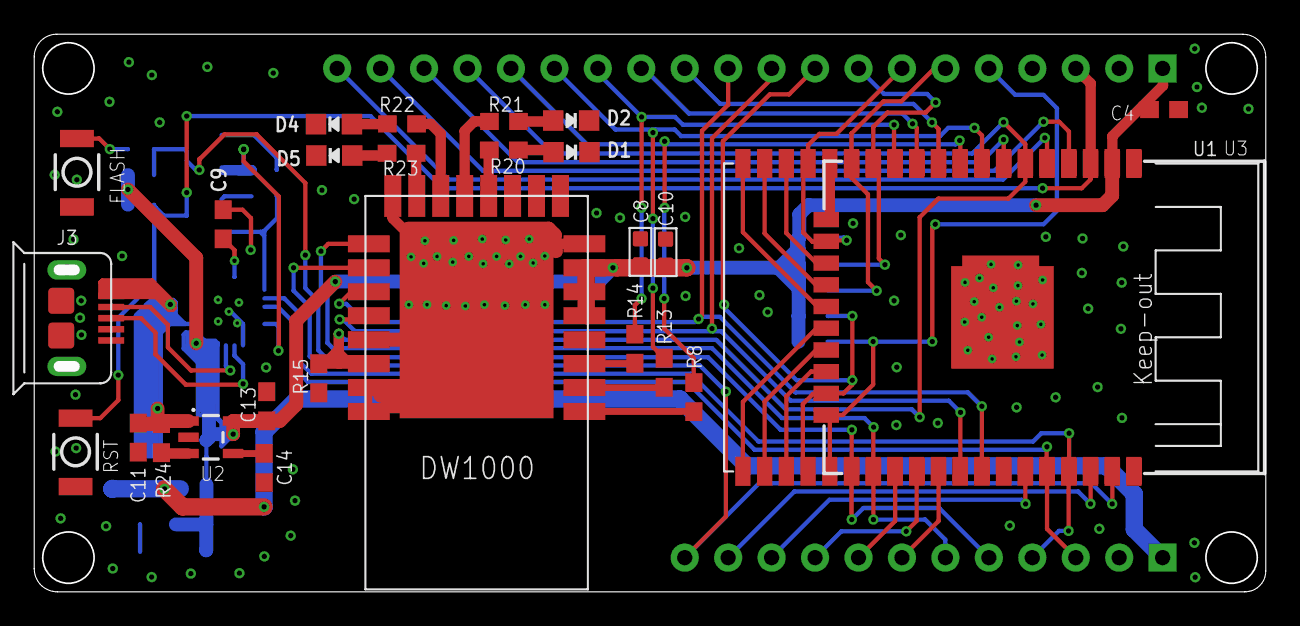
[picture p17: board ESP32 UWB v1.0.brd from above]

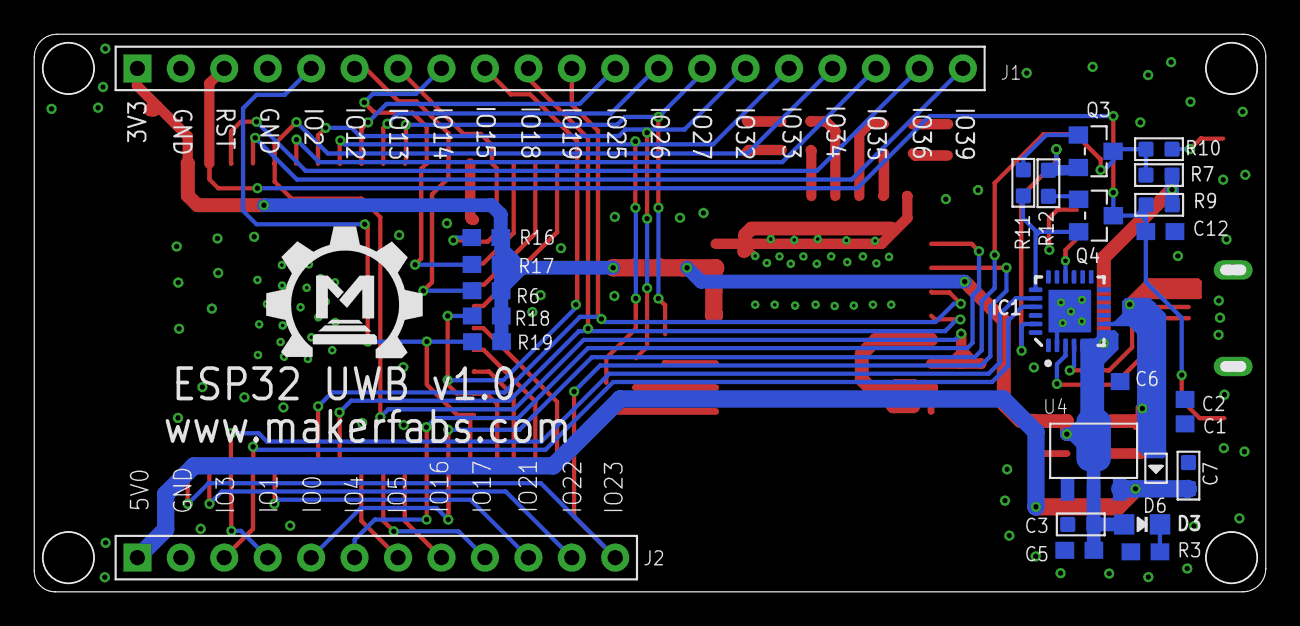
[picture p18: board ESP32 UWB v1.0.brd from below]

Board: 2 copper layers, 72.0 x 32.6 mm, 54 parts (27 on the bottom side), 60 nets.

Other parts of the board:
U$1: MAKERFABS_0.3

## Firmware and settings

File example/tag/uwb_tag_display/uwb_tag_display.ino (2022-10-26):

/*

For ESP32 UWB Pro with Display

*/

#include <SPI.h>
#include "DW1000Ranging.h"

#include <Wire.h>
#include <Adafruit_GFX.h>
#include <Adafruit_SSD1306.h>

#define TAG_ADDR "7D:00:22:EA:82:60:3B:9B"

// #define DEBUG

#define SPI_SCK 18
#define SPI_MISO 19
#define SPI_MOSI 23

#define UWB_RST 27 // reset pin
#define UWB_IRQ 34 // irq pin
#define UWB_SS 21   // spi select pin

#define I2C_SDA 4
#define I2C_SCL 5

struct Link
{
    uint16_t anchor_addr;
    float range;
    float dbm;
    struct Link *next;
};

struct Link *uwb_data;

Adafruit_SSD1306 display(128, 64, &Wire, -1);

void setup()
{
    Serial.begin(115200);

    Wire.begin(I2C_SDA, I2C_SCL);
    delay(1000);
    // SSD1306_SWITCHCAPVCC = generate display voltage from 3.3V internally
    if (!display.begin(SSD1306_SWITCHCAPVCC, 0x3C))
    { // Address 0x3C for 128x32
        Serial.println(F("SSD1306 allocation failed"));
        for (;;)
            ; // Don't proceed, loop forever
    }
    display.clearDisplay();

    logoshow();

    // init the configuration
    SPI.begin(SPI_SCK, SPI_MISO, SPI_MOSI);
    DW1000Ranging.initCommunication(UWB_RST, UWB_SS, UWB_IRQ); // Reset, CS, IRQ pin
    // define the sketch as anchor. It will be great to dynamically change the type of module
    DW1000Ranging.attachNewRange(newRange);
    DW1000Ranging.attachNewDevice(newDevice);
    DW1000Ranging.attachInactiveDevice(inactiveDevice);
    // Enable the filter to smooth the distance
    // DW1000Ranging.useRangeFilter(true);

    // we start the module as a tag
    DW1000Ranging.startAsTag(TAG_ADDR, DW1000.MODE_LONGDATA_RANGE_LOWPOWER);
    // DW1000Ranging.startAsTag(TAG_ADDR, DW1000.MODE_SHORTDATA_FAST_LOWPOWER);
    // DW1000Ranging.startAsTag(TAG_ADDR, DW1000.MODE_LONGDATA_FAST_LOWPOWER);
    // DW1000Ranging.startAsTag(TAG_ADDR, DW1000.MODE_SHORTDATA_FAST_ACCURACY);
    // DW1000Ranging.startAsTag(TAG_ADDR, DW1000.MODE_LONGDATA_FAST_ACCURACY);
    // DW1000Ranging.startAsTag(TAG_ADDR, DW1000.MODE_LONGDATA_RANGE_ACCURACY);

    uwb_data = init_link();
}

long int runtime = 0;

void loop()
{
    DW1000Ranging.loop();
    if ((millis() - runtime) > 1000)
    {
        display_uwb(uwb_data);
        runtime = millis();
    }
}

void newRange()
{
    Serial.print("from: ");
    Serial.print(DW1000Ranging.getDistantDevice()->getShortAddress(), HEX);
    Serial.print("\t Range: ");
    Serial.print(DW1000Ranging.getDistantDevice()->getRange());
    Serial.print(" m");
    Serial.print("\t RX power: ");
    Serial.print(DW1000Ranging.getDistantDevice()->getRXPower());
    Serial.println(" dBm");

    fresh_link(uwb_data, DW1000Ranging.getDistantDevice()->getShortAddress(), DW1000Ranging.getDistantDevice()->getRange(), DW1000Ranging.getDistantDevice()->getRXPower());
    // print_link(uwb_data);
}

void newDevice(DW1000Device *device)
{
    Serial.print("ranging init; 1 device added ! -> ");
    Serial.print(" short:");
    Serial.println(device->getShortAddress(), HEX);

    add_link(uwb_data, device->getShortAddress());
}

void inactiveDevice(DW1000Device *device)
{
    Serial.print("delete inactive device: ");
    Serial.println(device->getShortAddress(), HEX);

    delete_link(uwb_data, device->getShortAddress());
}

// Data Link

struct Link *init_link()
{
#ifdef DEBUG
    Serial.println("init_link");
#endif
    struct Link *p = (struct Link *)malloc(sizeof(struct Link));
    p->next = NULL;
    p->anchor_addr = 0;
    p->range = 0.0;

    return p;
}

void add_link(struct Link *p, uint16_t addr)
{
#ifdef DEBUG
    Serial.println("add_link");
#endif
    struct Link *temp = p;
    // Find struct Link end
    while (temp->next != NULL)
    {
        temp = temp->next;
    }

    Serial.println("add_link:find struct Link end");
    // Create a anchor
    struct Link *a = (struct Link *)malloc(sizeof(struct Link));
    a->anchor_addr = addr;
    a->range = 0.0;
    a->dbm = 0.0;
    a->next = NULL;

    // Add anchor to end of struct Link
    temp->next = a;

    return;
}

struct Link *find_link(struct Link *p, uint16_t addr)
{
#ifdef DEBUG
    Serial.println("find_link");
#endif
    if (addr == 0)
    {
        Serial.println("find_link:Input addr is 0");
        return NULL;
    }

    if (p->next == NULL)
    {
        Serial.println("find_link:Link is empty");
        return NULL;
    }

    struct Link *temp = p;
    // Find target struct Link or struct Link end
    while (temp->next != NULL)
    {
        temp = temp->next;
        if (temp->anchor_addr == addr)
        {
            // Serial.println("find_link:Find addr");
            return temp;
        }
    }

    Serial.println("find_link:Can't find addr");
    return NULL;
}

void fresh_link(struct Link *p, uint16_t addr, float range, float dbm)
{
#ifdef DEBUG
    Serial.println("fresh_link");
#endif
    struct Link *temp = find_link(p, addr);
    if (temp != NULL)
    {

        temp->range = range;
        temp->dbm = dbm;
        return;
    }
    else
    {
        Serial.println("fresh_link:Fresh fail");
        return;
    }
}

void print_link(struct Link *p)
{
#ifdef DEBUG
    Serial.println("print_link");
#endif
    struct Link *temp = p;

    while (temp->next != NULL)
    {
        // Serial.println("Dev %d:%d m", temp->next->anchor_addr, temp->next->range);
        Serial.println(temp->next->anchor_addr, HEX);
        Serial.println(temp->next->range);
        Serial.println(temp->next->dbm);
        temp = temp->next;
    }

    return;
}

void delete_link(struct Link *p, uint16_t addr)
{
#ifdef DEBUG
    Serial.println("delete_link");
#endif
    if (addr == 0)
        return;

    struct Link *temp = p;
    while (temp->next != NULL)
    {
        if (temp->next->anchor_addr == addr)
        {
            struct Link *del = temp->next;
            temp->next = del->next;
            free(del);
            return;
        }
        temp = temp->next;
    }
    return;
}

// SSD1306

void logoshow(void)
{
    display.clearDisplay();

    display.setTextSize(2);              // Normal 1:1 pixel scale
    display.setTextColor(SSD1306_WHITE); // Draw white text
    display.setCursor(0, 0);             // Start at top-left corner
    display.println(F("Makerfabs"));

    display.setTextSize(1);
    display.setCursor(0, 20); // Start at top-left corner
    display.println(F("DW1000 DEMO"));
    display.display();
    delay(2000);
}

void display_uwb(struct Link *p)
{
    struct Link *temp = p;
    int row = 0;

    display.clearDisplay();

    display.setTextColor(SSD1306_WHITE);

    if (temp->next == NULL)
    {
        display.setTextSize(2);
        display.setCursor(0, 0);
        display.println("No Anchor");
        display.display();
        return;
    }

    while (temp->next != NULL)
    {
        temp = temp->next;

        // Serial.println("Dev %d:%d m", temp->next->anchor_addr, temp->next->range);
        Serial.println(temp->anchor_addr, HEX);
        Serial.println(temp->range);

        char c[30];

        // sprintf(c, "%X:%.1f m %.1f", temp->anchor_addr, temp->range, temp->dbm);
        // sprintf(c, "%X:%.1f m", temp->anchor_addr, temp->range);
        sprintf(c, "%.1f m", temp->range);
        display.setTextSize(2);
        display.setCursor(0, row++ * 32); // Start at top-left corner
        display.println(c);

        display.println("");

        sprintf(c, "%.2f dbm", temp->dbm);
        display.setTextSize(2);
        display.println(c);

        if (row >= 1)
        {
            break;
        }
    }
    delay(100);
    display.display();
    return;
}

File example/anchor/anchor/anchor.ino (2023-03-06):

/*

For ESP32 UWB or ESP32 UWB Pro

*/

#include <SPI.h>
#include "DW1000Ranging.h"

#define ANCHOR_ADD "86:17:5B:D5:A9:9A:E2:9C"

#define SPI_SCK 18
#define SPI_MISO 19
#define SPI_MOSI 23
#define DW_CS 4

// connection pins
const uint8_t PIN_RST = 27; // reset pin
const uint8_t PIN_IRQ = 34; // irq pin
const uint8_t PIN_SS = 4;   // spi select pin

void setup()
{
    Serial.begin(115200);
    delay(1000);
    //init the configuration
    SPI.begin(SPI_SCK, SPI_MISO, SPI_MOSI);
    DW1000Ranging.initCommunication(PIN_RST, PIN_SS, PIN_IRQ); //Reset, CS, IRQ pin
    //define the sketch as anchor. It will be great to dynamically change the type of module
    DW1000Ranging.attachNewRange(newRange);
    DW1000Ranging.attachBlinkDevice(newBlink);
    DW1000Ranging.attachInactiveDevice(inactiveDevice);
    //Enable the filter to smooth the distance
    //DW1000Ranging.useRangeFilter(true);

    //we start the module as an anchor
    // DW1000Ranging.startAsAnchor("82:17:5B:D5:A9:9A:E2:9C", DW1000.MODE_LONGDATA_RANGE_ACCURACY);

    DW1000Ranging.startAsAnchor(ANCHOR_ADD, DW1000.MODE_LONGDATA_RANGE_LOWPOWER, false);
    // DW1000Ranging.startAsAnchor(ANCHOR_ADD, DW1000.MODE_SHORTDATA_FAST_LOWPOWER);
    // DW1000Ranging.startAsAnchor(ANCHOR_ADD, DW1000.MODE_LONGDATA_FAST_LOWPOWER);
    // DW1000Ranging.startAsAnchor(ANCHOR_ADD, DW1000.MODE_SHORTDATA_FAST_ACCURACY);
    // DW1000Ranging.startAsAnchor(ANCHOR_ADD, DW1000.MODE_LONGDATA_FAST_ACCURACY);
    // DW1000Ranging.startAsAnchor(ANCHOR_ADD, DW1000.MODE_LONGDATA_RANGE_ACCURACY);
}

void loop()
{
    DW1000Ranging.loop();
}

void newRange()
{
    Serial.print("from: ");
    Serial.print(DW1000Ranging.getDistantDevice()->getShortAddress(), HEX);
    Serial.print("\t Range: ");
    Serial.print(DW1000Ranging.getDistantDevice()->getRange());
    Serial.print(" m");
    Serial.print("\t RX power: ");
    Serial.print(DW1000Ranging.getDistantDevice()->getRXPower());
    Serial.println(" dBm");
}

void newBlink(DW1000Device *device)
{
    Serial.print("blink; 1 device added ! -> ");
    Serial.print(" short:");
    Serial.println(device->getShortAddress(), HEX);
}

void inactiveDevice(DW1000Device *device)
{
    Serial.print("delete inactive device: ");
    Serial.println(device->getShortAddress(), HEX);
}

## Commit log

2022-10-26 ESP32 UWB Pro with Display v1.2
    hardware
    [ESP32 UWB Pro with Display v1.2.brd, ESP32 UWB Pro with Display v1.2.sch]
2023-03-06 Fix pin set

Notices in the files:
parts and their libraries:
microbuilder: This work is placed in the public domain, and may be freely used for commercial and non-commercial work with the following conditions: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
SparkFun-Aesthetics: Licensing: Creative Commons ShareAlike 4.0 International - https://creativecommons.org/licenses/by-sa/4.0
